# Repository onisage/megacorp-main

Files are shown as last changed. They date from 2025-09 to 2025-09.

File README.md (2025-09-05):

# MEGACORP-main
For all MEGACORP-related projects.

Created in collaboration with [baconspoon](github.com/baconspoon85) and [apfel](https://github.com/kilipan).



## Row Stagger

rowStag

## Ortholinear

ortho

## Alpha Stagger

alphaStag

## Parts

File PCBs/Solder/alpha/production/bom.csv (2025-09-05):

Designator | Footprint | Quantity | Value | LCSC Part #
C_1V-DECOUP1, C_3V-DECOUP2, C_LD1, C_LD2 | 0402 | 4 | 1u
C_1V-DECOUP2, C_1V-DECOUP3, C_3V-DECOUP3, C_3V-DECOUP4, C_3V-DECOUP5, C_3V-DECOUP6, C_3V-DECOUP7, C_3V-DECOUP8, C_3V-DECOUP9, C_FLASH1 | 0402 | 10 | 100n
C_3V-DECOUP1 | 0402 | 1 | 10u
C_CRYSTAL1, C_CRYSTAL2 | 0402 | 2 | 22p
D1, D10, D11, D12, D13, D14, D15, D16, D17, D18, D19, D2, D20, D21, D22, D23, D24, D25, D26, D27, D28, D29, D3, D30, D31, D32, D33, D34, D35, D36, D37, D4, D5, D6, D7, D8, D9 | D_SOD-123 | 37 | 1N4148W
ENC1, ENC2 | ROT_Alps_EC11E-Switch | 2 | RotaryEncoder_Switch
J1 | JST_SH_SM04B-SRSS-TB_1x04-1MP_P1.00mm_Horizontal | 1 | SM04B-SRSS-TB(LF)(SN) | C160404
J4 | PinHeader_1x03_P2.54mm_Vertical | 1 | LED_STRIP
MX1, MX10, MX11, MX12, MX13, MX14, MX15, MX16, MX17, MX18, MX19, MX2, MX21, MX22, MX23, MX24, MX25, MX26, MX27, MX29, MX3, MX30, MX31, MX34, MX35, MX36, MX37, MX4, MX5, MX6, MX7, MX8, MX9 | SW_Hybrid_Cherry_MX_Alps_1.00u | 33 | MX-NoLED
MX20, MX28 | SW_Hybrid_Cherry_MX_Alps_1.50u | 2 | MX-NoLED
MX32, MX33 | SW_Hybrid_Cherry_MX_Alps_2.00u | 2 | MX-NoLED
R_CRYSTAL1, R_FLASH3 | 0402 | 2 | 1k
R_DATA1, R_DATA2 | 0402 | 2 | 27
R_FLASH1, R_FLASH2, R_RST1 | 0402 | 3 | 5k1
S1, S2 | STAB_MX_2u | 2 | MX_stab
SW1 | SW_SPST_TL3342 | 1 | RESET | C318884
SW2 | SW_SPST_TL3342 | 1 | BOOTSEL | C318884
U1 | QFN-56-1EP_7x7mm_P0.4mm_EP3.2x3.2mm_ThermalVias | 1 | RP2040 | C2040
U2 | SOIC-8_5.23x5.23mm_P1.27mm | 1 | W25Q128JVS | C2613930
U3 | SOT-23 | 1 | XC6206P332MR | C5446
U4 | SOT-563 | 1 | SN74LVC1T45DRL
Y1 | Crystal_SMD_3225-4Pin_3.2x2.5mm | 1 | 12MHz | C9002

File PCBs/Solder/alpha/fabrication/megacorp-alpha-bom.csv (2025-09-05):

Comment | Designator | Footprint | JLCPCB Part#(optional)
1uF | C_1V-Decoup1 | C_0402_1005Metric | C52923
100nF | C_1V-Decoup2 | C_0402_1005Metric | C2655418
100nF | C_1V-Decoup3 | C_0402_1005Metric | C2655418
10uF | C_3V-Decoup1 | C_0402_1005Metric | C19702
1uF | C_3V-Decoup2 | C_0402_1005Metric | C52923
100nF | C_3V-Decoup3 | C_0402_1005Metric | C2655418
100nF | C_3V-Decoup4 | C_0402_1005Metric | C2655418
100nF | C_3V-Decoup5 | C_0402_1005Metric | C2655418
100nF | C_3V-Decoup6 | C_0402_1005Metric | C2655418
100nF | C_3V-Decoup7 | C_0402_1005Metric | C2655418
100nF | C_3V-Decoup8 | C_0402_1005Metric | C2655418
100nF | C_3V-Decoup9 | C_0402_1005Metric | C2655418
22pF | C_Crystal1 | C_0402_1005Metric | C1555
22pF | C_Crystal2 | C_0402_1005Metric | C1555
100nF | C_Flash1 | C_0402_1005Metric | C2655418
1uF | C_LD1 | C_0402_1005Metric | C52923
1uF | C_LD2 | C_0402_1005Metric | C52923
1N4148W | D1 | D_SOD-123 | C81598
1N4148W | D2 | D_SOD-123 | C81598
1N4148W | D3 | D_SOD-123 | C81598
1N4148W | D4 | D_SOD-123 | C81598
1N4148W | D5 | D_SOD-123 | C81598
1N4148W | D6 | D_SOD-123 | C81598
1N4148W | D7 | D_SOD-123 | C81598
1N4148W | D8 | D_SOD-123 | C81598
1N4148W | D9 | D_SOD-123 | C81598
1N4148W | D10 | D_SOD-123 | C81598
1N4148W | D11 | D_SOD-123 | C81598
1N4148W | D12 | D_SOD-123 | C81598
1N4148W | D13 | D_SOD-123 | C81598
1N4148W | D14 | D_SOD-123 | C81598
1N4148W | D15 | D_SOD-123 | C81598
1N4148W | D16 | D_SOD-123 | C81598
1N4148W | D17 | D_SOD-123 | C81598
1N4148W | D18 | D_SOD-123 | C81598
1N4148W | D19 | D_SOD-123 | C81598
1N4148W | D20 | D_SOD-123 | C81598
1N4148W | D21 | D_SOD-123 | C81598
1N4148W | D22 | D_SOD-123 | C81598
1N4148W | D23 | D_SOD-123 | C81598
1N4148W | D24 | D_SOD-123 | C81598
1N4148W | D25 | D_SOD-123 | C81598
1N4148W | D26 | D_SOD-123 | C81598
1N4148W | D27 | D_SOD-123 | C81598
1N4148W | D28 | D_SOD-123 | C81598
1N4148W | D29 | D_SOD-123 | C81598
1N4148W | D30 | D_SOD-123 | C81598
1N4148W | D31 | D_SOD-123 | C81598
1N4148W | D32 | D_SOD-123 | C81598
1N4148W | D33 | D_SOD-123 | C81598
1N4148W | D34 | D_SOD-123 | C81598
1N4148W | D35 | D_SOD-123 | C81598
1N4148W | D36 | D_SOD-123 | C81598
1N4148W | D37 | D_SOD-123 | C81598
SM04B-SRSS-TB(LF)(SN) | J1 | JST_SH_SM04B-SRSS-TB_1x04-1MP_P1.00mm_Horizontal | C160404
1k | R_Crystal1 | R_0402_1005Metric | C279987
27 | R_DATA1 | R_0402_1005Metric | C25100
27 | R_DATA2 | R_0402_1005Metric | C25100
5k1 | R_Flash1 | R_0402_1005Metric | C103086
5k1 | R_Flash2 | R_0402_1005Metric | C103086
1k | R_Flash3 | R_0402_1005Metric | C279987
5k1 | R_RST1 | R_0402_1005Metric | C103086
RESET | SW1 | SW_SPST_TL3342 | C318884
BOOTSEL | SW2 | SW_SPST_TL3342 | C318884
RP2040 | U1 | QFN-56-1EP_7x7mm_P0.4mm_EP3.2x3.2mm_ThermalVias | C2040
W25Q128JVS | U2 | SOIC-8_5.23x5.23mm_P1.27mm | C2613930
XC6206P332MR | U3 | SOT-23 | C6430947
12MHz | Y1 | Crystal_SMD_3225-4Pin_3.2x2.5mm | C9002

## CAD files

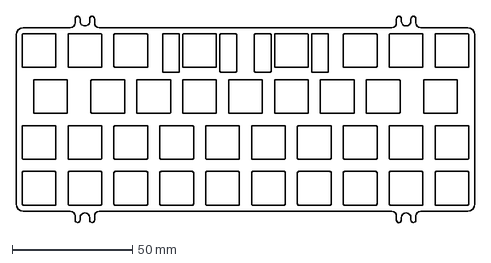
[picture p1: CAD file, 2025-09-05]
Plates/DXF/Alpha Stagger.dxf
190.4 x 85.7 mm

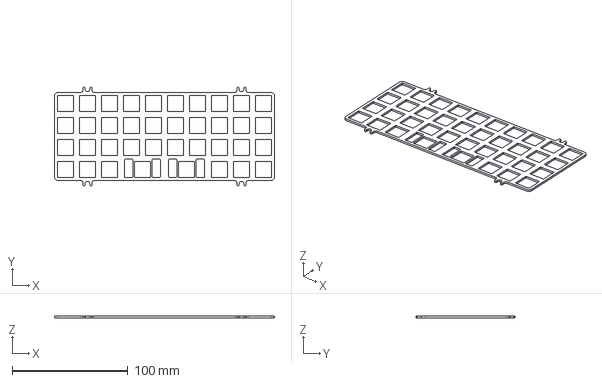
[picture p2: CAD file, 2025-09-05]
Plates/Ortholinear 1.6mm.step
190.4 x 85.7 x 1.60 mm

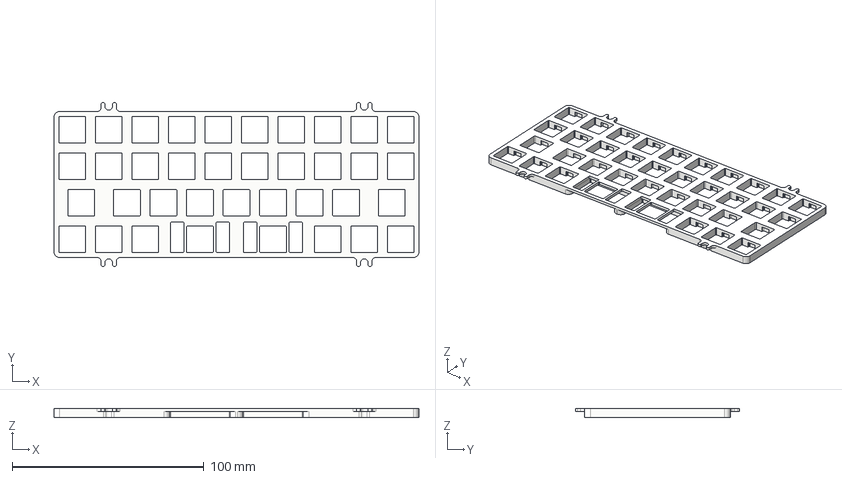
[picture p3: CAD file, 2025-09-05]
Plates/Alpha Stagger 4.7mm.step
190.4 x 85.7 x 4.70 mm

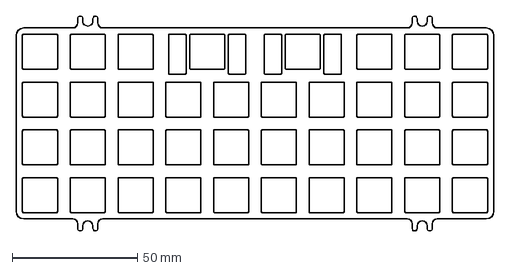
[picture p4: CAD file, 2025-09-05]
Plates/DXF/Ortholinear.dxf
190.4 x 85.7 mm

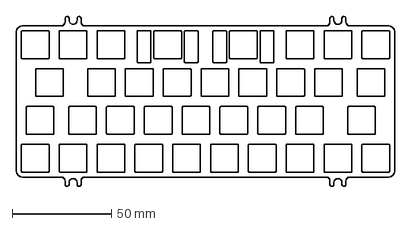
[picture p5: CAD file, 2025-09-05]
Plates/DXF/Row Stagger.dxf
190.4 x 85.7 mm

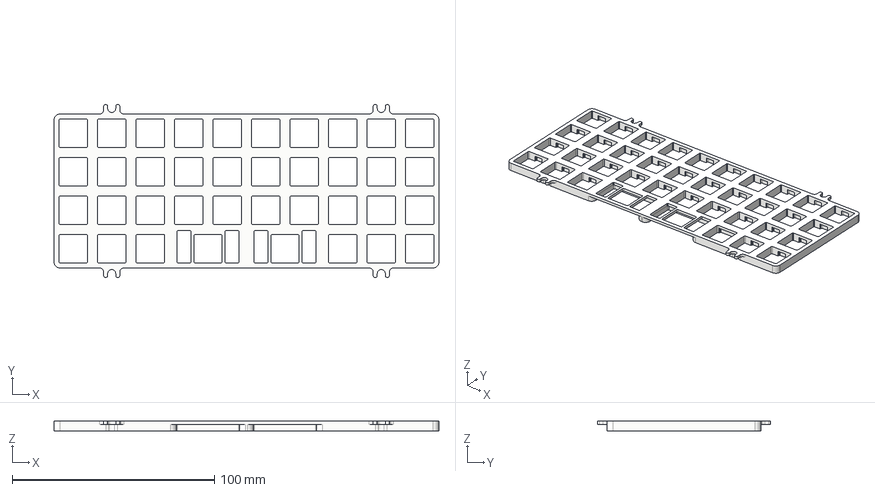
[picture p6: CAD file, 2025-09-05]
Plates/Ortholinear 4.7mm.step
190.4 x 85.7 x 4.70 mm

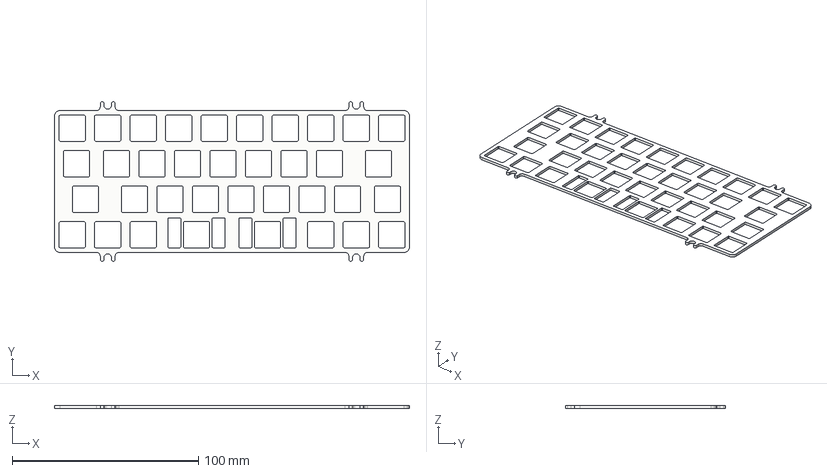
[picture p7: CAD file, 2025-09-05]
Plates/Row Stagger 1.6mm.step
190.4 x 85.7 x 1.60 mm

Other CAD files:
Plates/Alpha Stagger 1.6mm.step
Plates/Row Stagger 4.7mm.step

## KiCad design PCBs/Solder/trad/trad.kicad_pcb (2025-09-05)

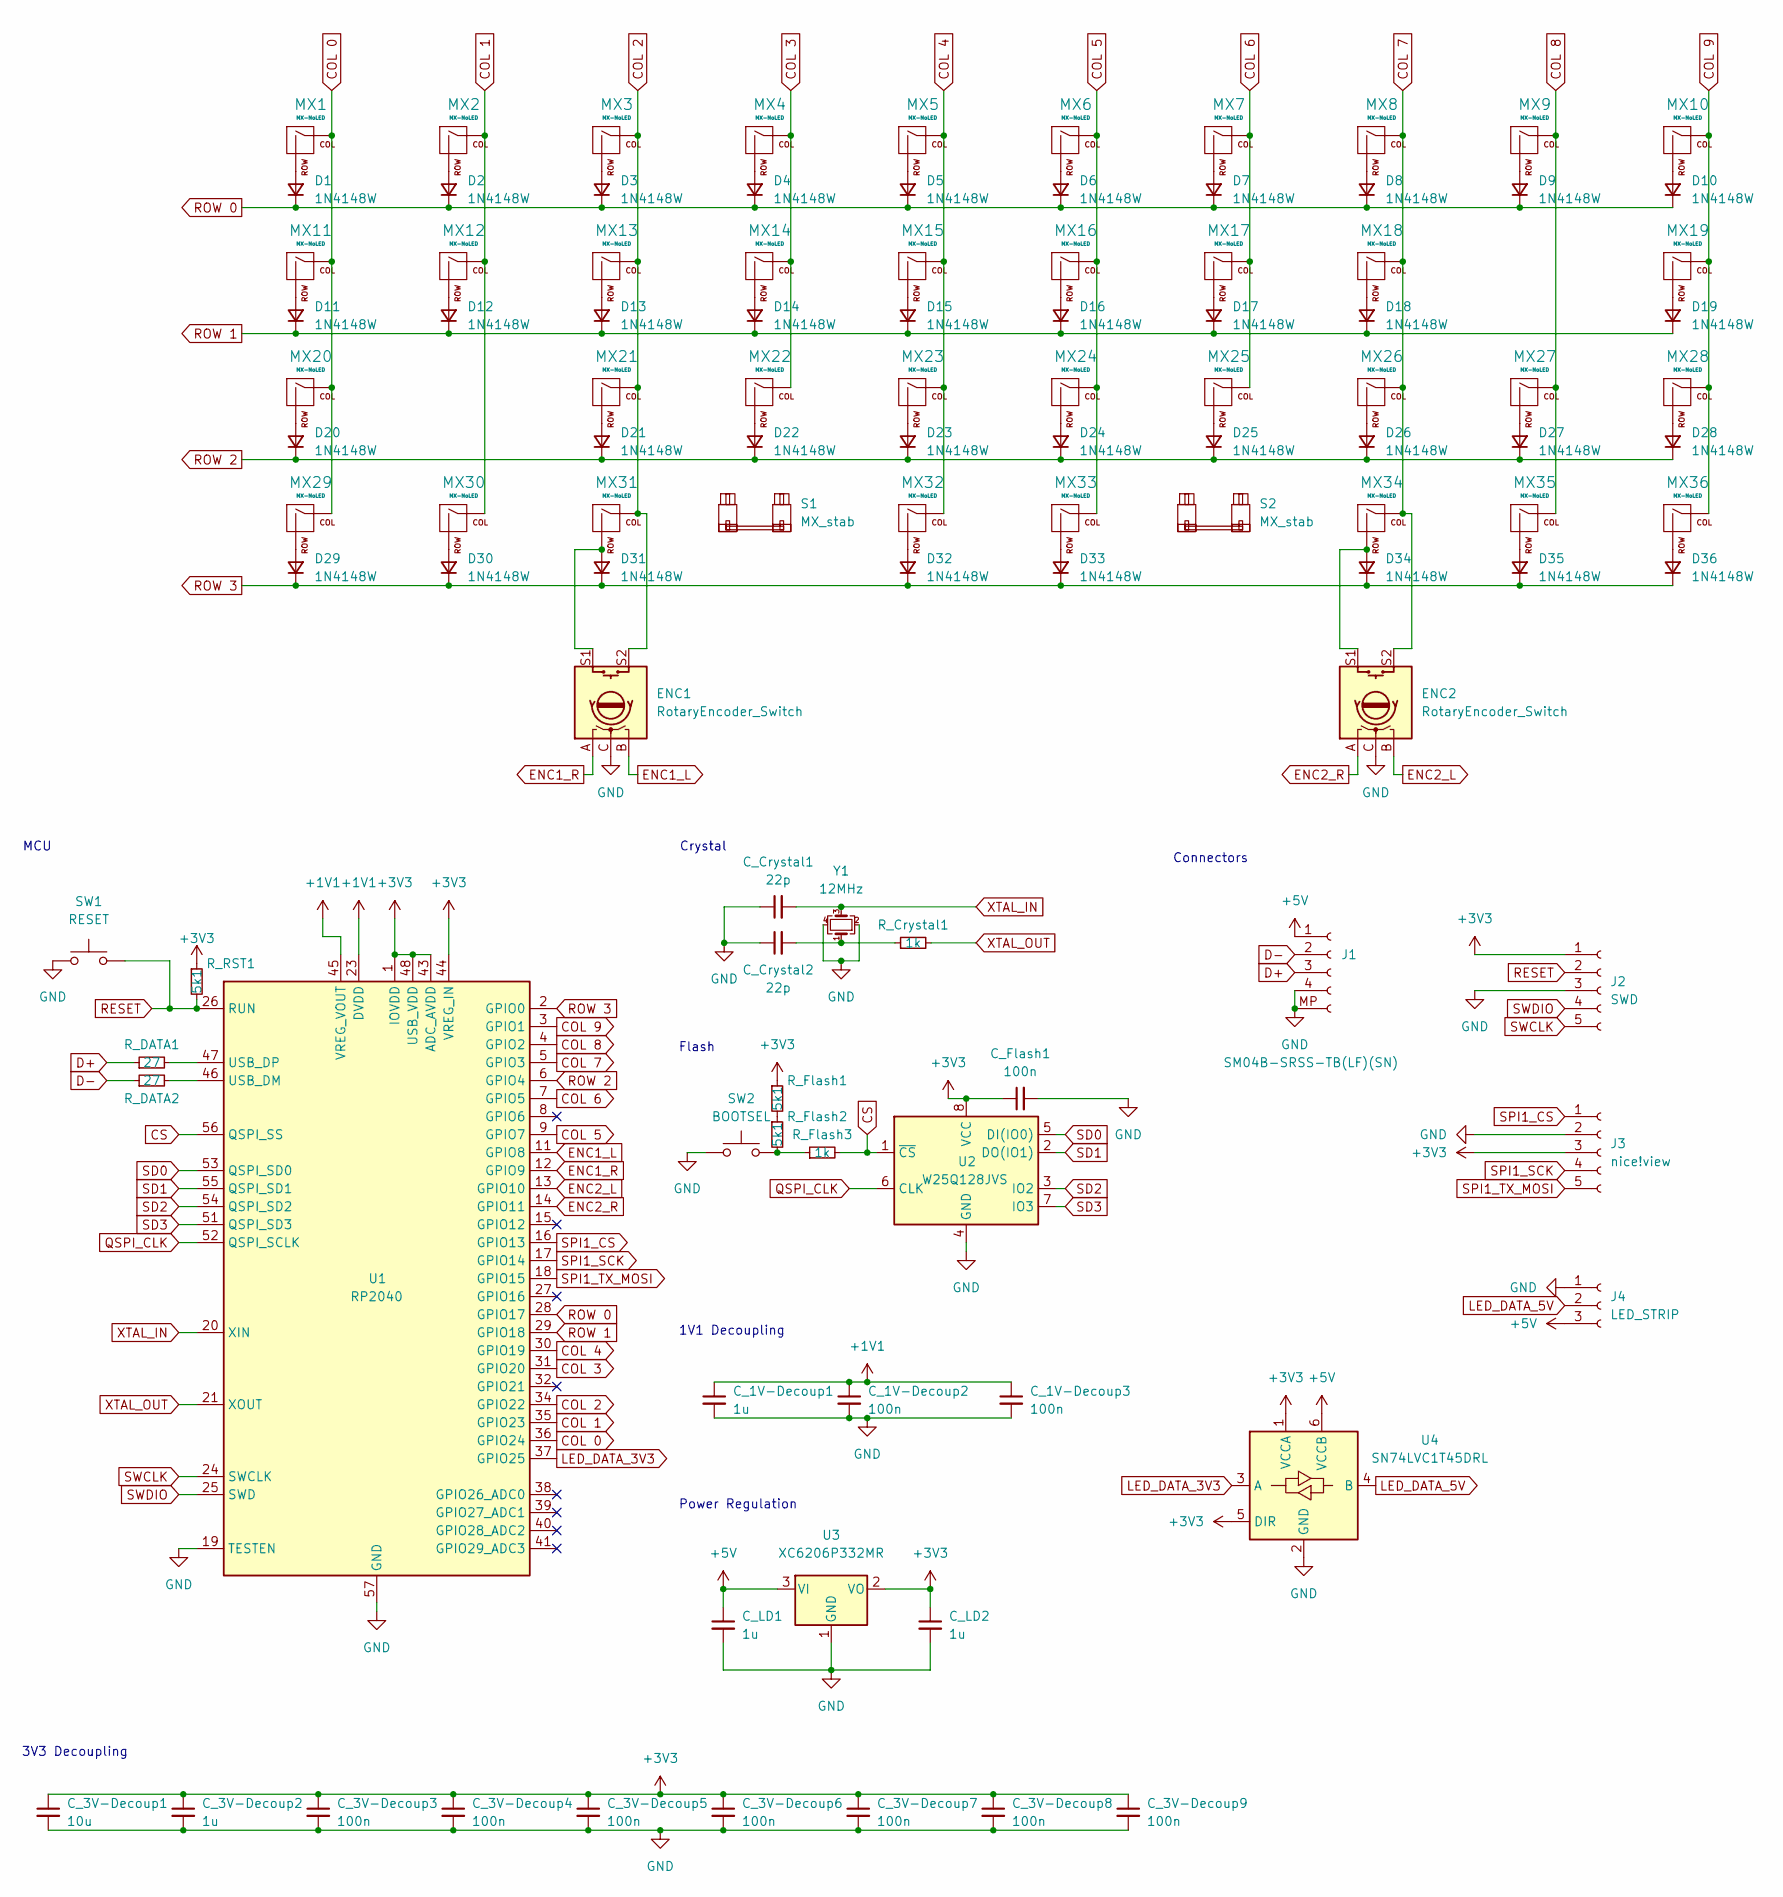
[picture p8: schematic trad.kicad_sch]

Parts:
C_1V-Decoup1, C_3V-Decoup2: 1u; C_0402_1005Metric
C_1V-Decoup2, C_1V-Decoup3, C_3V-Decoup3, C_3V-Decoup4, C_3V-Decoup5, C_3V-Decoup6, C_3V-Decoup7, C_3V-Decoup8, C_3V-Decoup9: 100n; C_0402_1005Metric
C_3V-Decoup1: 10u; C_0402_1005Metric
C_Crystal1, C_Crystal2: 22p; C_0402_1005Metric
C_Flash1: 100n; C_0402_1005Metric
C_LD1, C_LD2: 1u; C_0402_1005Metric
D1, D2, D3, D4, D5, D6, D7, D8, D9, D10, D11, D12, D13, D14, D15, D16, D17, D18, D19, D20, D21, D22, D23, D24, D25, D26, D27, D28, D29, D30, D31, D32, D33, D34, D35, D36: 1N4148W; D_SOD-123
ENC1, ENC2: RotaryEncoder_Switch; ROT_Alps_EC11E-Switch
J1: SM04B-SRSS-TB(LF)(SN); JST_SH_SM04B-SRSS-TB_1x04-1MP_P1.00mm_Horizontal; LCSC C160404
J2: SWD; PinHeader_1x05_P2.54mm_Vertical
J3: nice!view; PinHeader_1x05_P2.54mm_Vertical
J4: LED_STRIP; PinHeader_1x03_P2.54mm_Vertical
MX1, MX2, MX3, MX4, MX5, MX6, MX7, MX8, MX9, MX10, MX12, MX13, MX14, MX15, MX16, MX17, MX18, MX21, MX22, MX23, MX24, MX25, MX26, MX27, MX29, MX30, MX31, MX34, MX35, MX36: MX-NoLED; SW_Hybrid_Cherry_MX_Alps_1.00u
MX11, MX28: MX-NoLED; SW_Hybrid_Cherry_MX_Alps_1.25u
MX19, MX20: MX-NoLED; SW_Hybrid_Cherry_MX_Alps_1.75u
MX32, MX33: MX-NoLED; SW_Hybrid_Cherry_MX_Alps_2.00u
R_Crystal1: 1k; R_0402_1005Metric
R_DATA1, R_DATA2: 27; R_0402_1005Metric
R_Flash1, R_Flash2: 5k1; R_0402_1005Metric
R_Flash3: 1k; R_0402_1005Metric
R_RST1: 5k1; R_0402_1005Metric
S1, S2: MX_stab; STAB_MX_2u
SW1: RESET; SW_SPST_TL3342; LCSC C318884
SW2: BOOTSEL; SW_SPST_TL3342; LCSC C318884
U1: RP2040; QFN-56-1EP_7x7mm_P0.4mm_EP3.2x3.2mm_ThermalVias; LCSC C2040
U2: W25Q128JVS; SOIC-8_5.23x5.23mm_P1.27mm; LCSC C2613930
U3: XC6206P332MR; SOT-23; LCSC C5446
U4: SN74LVC1T45DRL; SOT-563
Y1: 12MHz; Crystal_SMD_3225-4Pin_3.2x2.5mm; LCSC C9002

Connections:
+1V1: C_1V-Decoup1.1, C_1V-Decoup2.1, C_1V-Decoup3.1, U1.23 (DVDD), U1.45 (VREG_VOUT), U1.50 (DVDD)
+3V3: C_3V-Decoup1.1, C_3V-Decoup2.1, C_3V-Decoup3.1, C_3V-Decoup4.1, C_3V-Decoup5.1, C_3V-Decoup6.1, C_3V-Decoup7.1, C_3V-Decoup8.1, C_3V-Decoup9.1, C_Flash1.1, C_LD2.1, J2.1, J3.3, R_Flash1.1, R_RST1.1, U1.1 (IOVDD), U1.10 (IOVDD), U1.22 (IOVDD), U1.33 (IOVDD), U1.42 (IOVDD), U1.43 (ADC_AVDD), U1.44 (VREG_IN), U1.48 (USB_VDD), U1.49 (IOVDD), U2.8 (VCC), U3.2 (VO), U4.1 (VCCA), U4.5 (DIR)
+5V: C_LD1.1, J1.1, J4.3, U3.3 (VI), U4.6 (VCCB)
COL 0: MX1.1 (COL), MX11.1 (COL), MX20.1 (COL), MX29.1 (COL), U1.36 (GPIO24)
COL 1: MX2.1 (COL), MX12.1 (COL), MX30.1 (COL), U1.35 (GPIO23)
COL 2: ENC1.S2, MX3.1 (COL), MX13.1 (COL), MX21.1 (COL), MX31.1 (COL), U1.34 (GPIO22)
COL 3: MX4.1 (COL), MX14.1 (COL), MX22.1 (COL), U1.31 (GPIO20)
COL 4: MX5.1 (COL), MX15.1 (COL), MX23.1 (COL), MX32.1 (COL), U1.30 (GPIO19)
COL 5: MX6.1 (COL), MX16.1 (COL), MX24.1 (COL), MX33.1 (COL), U1.9 (GPIO7)
COL 6: MX7.1 (COL), MX17.1 (COL), MX25.1 (COL), U1.7 (GPIO5)
COL 7: ENC2.S2, MX8.1 (COL), MX18.1 (COL), MX26.1 (COL), MX34.1 (COL), U1.5 (GPIO3)
COL 8: MX9.1 (COL), MX27.1 (COL), MX35.1 (COL), U1.4 (GPIO2)
COL 9: MX10.1 (COL), MX19.1 (COL), MX28.1 (COL), MX36.1 (COL), U1.3 (GPIO1)
CS: R_Flash3.2, U1.56 (QSPI_SS), U2.1 (~CS)
D+: J1.3, R_DATA1.1
D-: J1.2, R_DATA2.1
ENC1_L: ENC1.B, U1.11 (GPIO8)
ENC1_R: ENC1.A, U1.12 (GPIO9)
ENC2_L: ENC2.B, U1.13 (GPIO10)
ENC2_R: ENC2.A, U1.14 (GPIO11)
GND: C_1V-Decoup1.2, C_1V-Decoup2.2, C_1V-Decoup3.2, C_3V-Decoup1.2, C_3V-Decoup2.2, C_3V-Decoup3.2, C_3V-Decoup4.2, C_3V-Decoup5.2, C_3V-Decoup6.2, C_3V-Decoup7.2, C_3V-Decoup8.2, C_3V-Decoup9.2, C_Crystal1.1, C_Crystal2.1, C_Flash1.2, C_LD1.2, C_LD2.2, ENC1.C, ENC2.C, J1.4, J1.MP, J2.3, J3.2, J4.1, SW1.1, SW2.1, U1.19 (TESTEN), U1.57 (GND), U2.4 (GND), U3.1 (GND), U4.2 (GND), Y1.2, Y1.4
LED_DATA_3V3: U1.37 (GPIO25), U4.3 (A)
LED_DATA_5V: J4.2, U4.4 (B)
unnamed: C_Crystal2.2, R_Crystal1.1, Y1.1
unnamed: D1.2 (A), MX1.2 (ROW)
unnamed: D2.2 (A), MX2.2 (ROW)
unnamed: D3.2 (A), MX3.2 (ROW)
unnamed: D4.2 (A), MX4.2 (ROW)
unnamed: D5.2 (A), MX5.2 (ROW)
unnamed: D6.2 (A), MX6.2 (ROW)
unnamed: D7.2 (A), MX7.2 (ROW)
unnamed: D8.2 (A), MX8.2 (ROW)
unnamed: D9.2 (A), MX9.2 (ROW)
unnamed: D10.2 (A), MX10.2 (ROW)
unnamed: D11.2 (A), MX11.2 (ROW)
unnamed: D12.2 (A), MX12.2 (ROW)
unnamed: D13.2 (A), MX13.2 (ROW)
unnamed: D14.2 (A), MX14.2 (ROW)
unnamed: D15.2 (A), MX15.2 (ROW)
unnamed: D16.2 (A), MX16.2 (ROW)
unnamed: D17.2 (A), MX17.2 (ROW)
unnamed: D18.2 (A), MX18.2 (ROW)
unnamed: D19.2 (A), MX19.2 (ROW)
unnamed: D20.2 (A), MX20.2 (ROW)
unnamed: D21.2 (A), MX21.2 (ROW)
unnamed: D22.2 (A), MX22.2 (ROW)
unnamed: D23.2 (A), MX23.2 (ROW)
unnamed: D24.2 (A), MX24.2 (ROW)
unnamed: D25.2 (A), MX25.2 (ROW)
unnamed: D26.2 (A), MX26.2 (ROW)
unnamed: D27.2 (A), MX27.2 (ROW)
unnamed: D28.2 (A), MX28.2 (ROW)
unnamed: D29.2 (A), MX29.2 (ROW)
unnamed: D30.2 (A), MX30.2 (ROW)
unnamed: D31.2 (A), ENC1.S1, MX31.2 (ROW)
unnamed: D32.2 (A), MX32.2 (ROW)
unnamed: D33.2 (A), MX33.2 (ROW)
unnamed: D34.2 (A), ENC2.S1, MX34.2 (ROW)
unnamed: D35.2 (A), MX35.2 (ROW)
unnamed: D36.2 (A), MX36.2 (ROW)
unnamed: R_Flash1.2, R_Flash2.1
unnamed: R_Flash2.2, R_Flash3.1, SW2.2
unnamed: R_DATA2.2, U1.46 (USB_DM)
unnamed: R_DATA1.2, U1.47 (USB_DP)
QSPI_CLK: U1.52 (QSPI_SCLK), U2.6 (CLK)
RESET: J2.2, R_RST1.2, SW1.2, U1.26 (RUN)
ROW 0: D1.1 (K), D2.1 (K), D3.1 (K), D4.1 (K), D5.1 (K), D6.1 (K), D7.1 (K), D8.1 (K), D9.1 (K), D10.1 (K), U1.28 (GPIO17)
ROW 1: D11.1 (K), D12.1 (K), D13.1 (K), D14.1 (K), D15.1 (K), D16.1 (K), D17.1 (K), D18.1 (K), D19.1 (K), U1.29 (GPIO18)
ROW 2: D20.1 (K), D21.1 (K), D22.1 (K), D23.1 (K), D24.1 (K), D25.1 (K), D26.1 (K), D27.1 (K), D28.1 (K), U1.6 (GPIO4)
ROW 3: D29.1 (K), D30.1 (K), D31.1 (K), D32.1 (K), D33.1 (K), D34.1 (K), D35.1 (K), D36.1 (K), U1.2 (GPIO0)
SD0: U1.53 (QSPI_SD0), U2.5 (DI(IO0))
SD1: U1.55 (QSPI_SD1), U2.2 (DO(IO1))
SD2: U1.54 (QSPI_SD2), U2.3 (IO2)
SD3: U1.51 (QSPI_SD3), U2.7 (IO3)
SPI1_CS: J3.1, U1.16 (GPIO13)
SPI1_SCK: J3.4, U1.17 (GPIO14)
SPI1_TX_MOSI: J3.5, U1.18 (GPIO15)
SWCLK: J2.5, U1.24 (SWCLK)
SWDIO: J2.4, U1.25 (SWD)
XTAL_IN: C_Crystal1.2, U1.20 (XIN), Y1.3
XTAL_OUT: R_Crystal1.2, U1.21 (XOUT)

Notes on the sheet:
Power Regulation
Flash
MCU
3V3 Decoupling
Connectors
1V1 Decoupling
Crystal

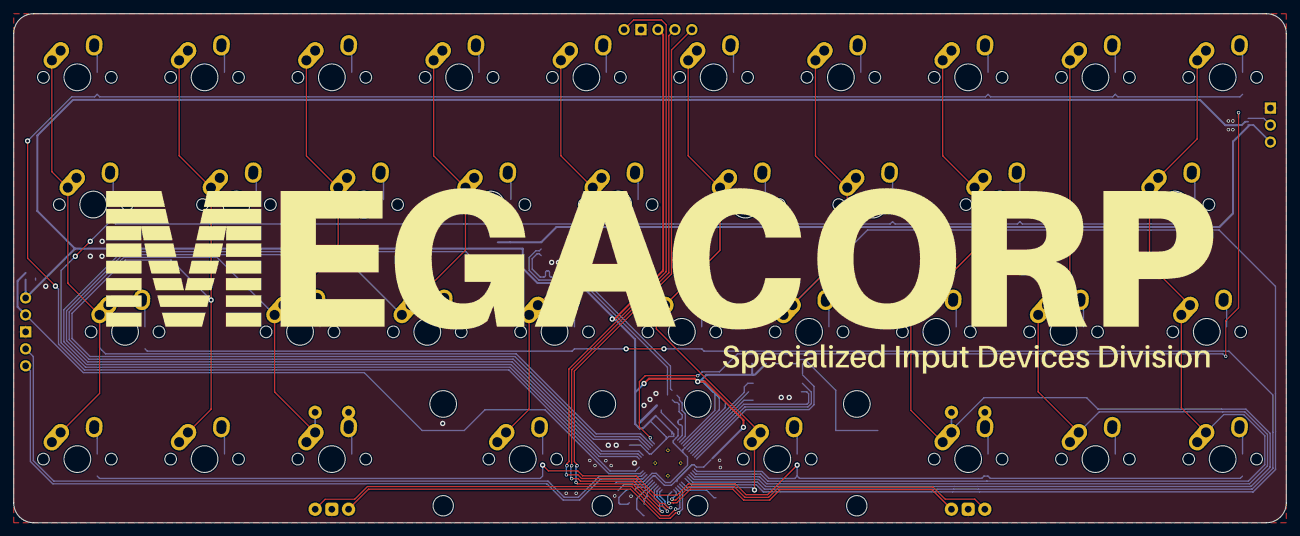
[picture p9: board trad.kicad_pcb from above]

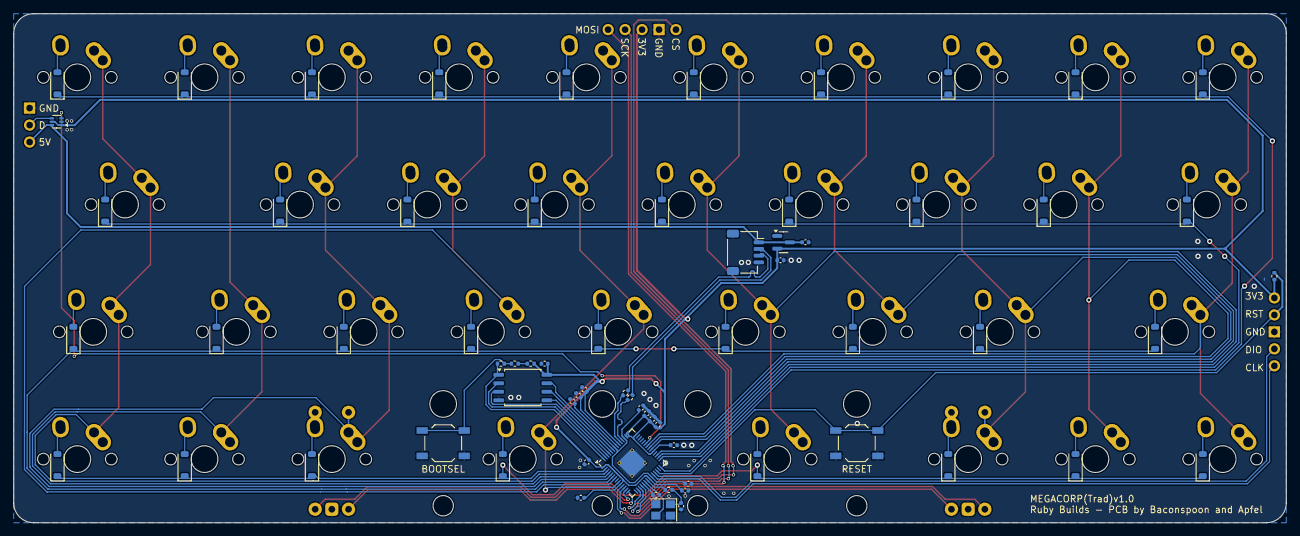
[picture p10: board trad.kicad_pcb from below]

Board: 2 copper layers, 190.5 x 76.2 mm, 111 parts (69 on the bottom side), 81 nets.

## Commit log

2025-09-05 Delete MEGACORP-solder/MEGACORP-main directory
    Incomplete Upload
    [alpha-B_Cu.gbl, alpha-B_Mask.gbs, alpha-B_Paste.gbp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]
2025-09-05 Delete MEGACORP-hotswap/MEGACORP-main/alpha_hs directory
    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
    [alpha_hs-B_Cu.gbl, alpha_hs-B_Mask.gbs, alpha_hs-B_Paste.gbp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]
